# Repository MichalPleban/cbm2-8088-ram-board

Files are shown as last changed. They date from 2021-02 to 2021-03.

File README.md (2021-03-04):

# CBM-II 8088 CPU + RAM expansion board

## About the project

This repository is the hardware part of the project to create a PC compatibility system for Commodore CBM-II computers. The software counterpart is located at:

https://github.com/MichalPleban/cbm2-pc-emulator

More information about the project can be found at:

http://www.cbm-ii.com/

## About the board

The board is a replica of the original 8088 processor board for Commodore CBM-II computers. The replica is 100% compatible with the original card, so you can still run original MS-DOS 1.25 or CP/M-86 1.1 on it.

Several additional features were added to the card which allow for building a system that has enough power to run modern versions of DOS and DOS software:

### Fixed stability problems

The original card has serious stability problems in many machines, and it simply refuses to run on most low-profile CBM-II computers. These problems are caused by noise on /ERAS and /ECAS signals which cause memory corruption. Depending on the computer motherboard and/or PLA, the card may either work without any problems, hang once every few minutes or simply not work at all.

These problems are removed in the replica, and it works in all CBM-II computers.

### 1 MB memory expansion

The expanded memory is visible to both CPUs and allows DOS to access full 640 kB of memory – running DOS in only 256 kB leaves too little room for almost any application. The 64 kB segments above the 640 kB barrier can be individually turned off to allow other hardware (such as ISA graphics cards) to map into the address space.

The card has also the cartridge ROM with “fast boot” KERNAL modifications, thanks to which the memory test during powerup is greatly shortened (the test of 1 MB memory with the original would take around 2 minutes – this is shortened to mere 4 seconds).

### 12 MHz system clock

The card is equipped with a clock generator that produces either 12 MHz system clock with 50% duty cycle (for the NEC V20 processor) or 8 MHz clock with 33% duty cycle (for the 8088 processor). Compared with the 5 MHz on the original card, it gives a much faster system.
The system speed is further increased by using SRAM chips, which do not require refresh. Therefore the memory refresh system does not steal cycles from the CPU like on the original card.

### Hardware SPI interface

The SPI system is used to create a fast interface to a SD card, which serves as a 8 GB hard disk. Because the interface is implemented in hardware using shift registers, in combination with the INS/OUTS instructions of the NEC V20 CPU, it allows for theoretical read and write speed exceeding 1 MB / s.

### Battery backed RTC clock

The clock keeps the date and time for DOS and has also a few bytes of battery backed NVRAM to hold persistent configuration data.

### Reprogrammable EEPROM

The PC compatibility software is stored in an EEPROM chip, which can be reprogrammed from the 8088 side. Thanks to this, The library can be upgraded just by putting a newer version on the SD card and running the upgrade program from within DOS.

Having the whole software in the EEPROM allows also for diskless boot – the whole software is loaded from ROM, not from the disk like with the original card.

### Expansion port

The expansion port contains all the CPU bus signals, which should make it possible to add an ISA interface in the future. A smaller port with just the SPI and I2C signals is also available for additional hardware expansions in the future.

### Support for hardware virtualization

The card can generate NMI signal whenever an I/O port is accessed by the 8088 CPU. The I/O port access and the value being written to it are stored in hardware latches, so that the NMI routine can determine which I/O port was accessed and perform appropriate actions to simulate the hardware.

A video memory access latch was also added, which holds information about which parts of the video buffer at segment 0B000h was modified. This information speeds up screen refresh, because only the modified parts are being refreshed.

### 8087 coprocessor compatibility
The original card had a bug, due to which using the 8087 FPU was not possible – the card would lock up when the FPU was inserted into its socket. This bug has been fixed in the replica.

### Unobtainable chips replaced

The original card uses the 6525 Tri-Port Interface chip which is impossible to obtain. It has been replaced by an 8255 chip.

### Cartridge ROM sockets
The card has sockets for cartridge ROM or RAM at $4000, $6000 and $C000 which allow using  existing cartridge images. If a cartridge ROM is present, the card boot menu allows selecting whether to boot into BASIC or start the cartridge.

## Building the card

The PCB of the board has 4 layers to make it smaller and fit into the small space inside the low-profile CBM-II machines. Check with your PCB factory if they can make a 4 layer PCB for you.

The board contains an Atmel ATF1508 CPLD chip. You need a suitable programmer, such as ATF15xx-DK2, to program the chip. The board has a JEDEC connector which can be used to connect to the programmer directly. Use the cobalt.jed file from the repository to program the chip.

There are two ROM images in the archive which are necessary for the card to work:
-	8088.bin – 27C512 chip image to be placed at U7D
-	6509.bin  - 27C64 chip image to be placed at U2C

There are also chargen_lp.bin and chargen_hp.bin images which can be used to replace the character ROM in your machine (correspondently for low-profile and high-profile machines). They contain an alternate character set with some characters that are useful when running DOS (such as the backspace character). The card must be configured to use this character set – press F10 after booting the card.

The freedos.zip archive contains an image of a bootable FreeDOS hard disk. Put this image onto an SD card that is at least 8 GB of size (there are several SD card imaging applications available, I am using Win32 Disk Imager). After writing the images, the SD card will be readable on your PC, so you can easily add other applications. Note that you must use this image to boot the 8088 card, because the SD card must be formatted with special geometry for the INT 13h functions in the 8088 BIOS.

The ROM image from the repository contains the current version of the PC compatibility library. If you want to update the library in the future, grab the upgrade.com file from the repository, put it on the SD card and run it in DOS – it will write the newest version to the EEPROM chip on the board.

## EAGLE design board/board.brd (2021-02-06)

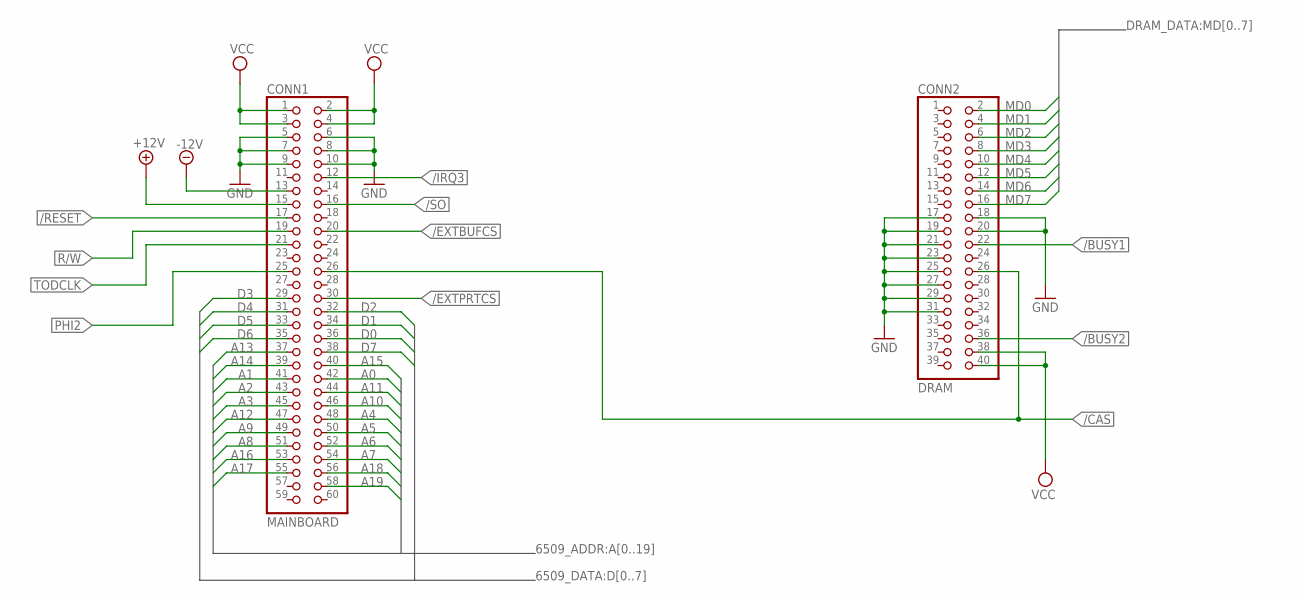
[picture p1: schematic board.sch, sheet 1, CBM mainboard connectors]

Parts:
CONN1: MAINBOARD; 2X30
CONN2: DRAM; 2X20

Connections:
+12V: CONN1.15; also elsewhere on the board
-12V: CONN1.13; also elsewhere on the board
/BUSY1: CONN2.22; also elsewhere on the board
/BUSY2: CONN2.36; also elsewhere on the board
/CAS: CONN1.26, CONN2.26; also elsewhere on the board
/EXTBUFCS: CONN1.20; also elsewhere on the board
/EXTPRTCS: CONN1.30; also elsewhere on the board
/IRQ3: CONN1.12; also elsewhere on the board
/RESET: CONN1.17; also elsewhere on the board
/SO: CONN1.16; also elsewhere on the board
A0: CONN1.42; also elsewhere on the board
A1: CONN1.41; also elsewhere on the board
A2: CONN1.43; also elsewhere on the board
A3: CONN1.45; also elsewhere on the board
A4: CONN1.48; also elsewhere on the board
A5: CONN1.50; also elsewhere on the board
A6: CONN1.52; also elsewhere on the board
A7: CONN1.54; also elsewhere on the board
A8: CONN1.51; also elsewhere on the board
A9: CONN1.49; also elsewhere on the board
A10: CONN1.46; also elsewhere on the board
A11: CONN1.44; also elsewhere on the board
A12: CONN1.47; also elsewhere on the board
A13: CONN1.37; also elsewhere on the board
A14: CONN1.39; also elsewhere on the board
A15: CONN1.40; also elsewhere on the board
A16: CONN1.53; also elsewhere on the board
A17: CONN1.55; also elsewhere on the board
A18: CONN1.56; also elsewhere on the board
A19: CONN1.58; also elsewhere on the board
D0: CONN1.36; also elsewhere on the board
D1: CONN1.34; also elsewhere on the board
D2: CONN1.32; also elsewhere on the board
D3: CONN1.29; also elsewhere on the board
D4: CONN1.31; also elsewhere on the board
D5: CONN1.33; also elsewhere on the board
D6: CONN1.35; also elsewhere on the board
D7: CONN1.38; also elsewhere on the board
GND: CONN1.5, CONN1.6, CONN1.7, CONN1.8, CONN1.9, CONN1.10, CONN2.17, CONN2.18, CONN2.19, CONN2.20, CONN2.21, CONN2.23, CONN2.25, CONN2.27, CONN2.29, CONN2.31; also elsewhere on the board
MD0: CONN2.2; also elsewhere on the board
MD1: CONN2.4; also elsewhere on the board
MD2: CONN2.6; also elsewhere on the board
MD3: CONN2.8; also elsewhere on the board
MD4: CONN2.10; also elsewhere on the board
MD5: CONN2.12; also elsewhere on the board
MD6: CONN2.14; also elsewhere on the board
MD7: CONN2.16; also elsewhere on the board
PHI2: CONN1.25; also elsewhere on the board
R/W: CONN1.19; also elsewhere on the board
TODCLK: CONN1.21; also elsewhere on the board
VCC: CONN1.1, CONN1.2, CONN1.3, CONN1.4, CONN2.38, CONN2.40; also elsewhere on the board

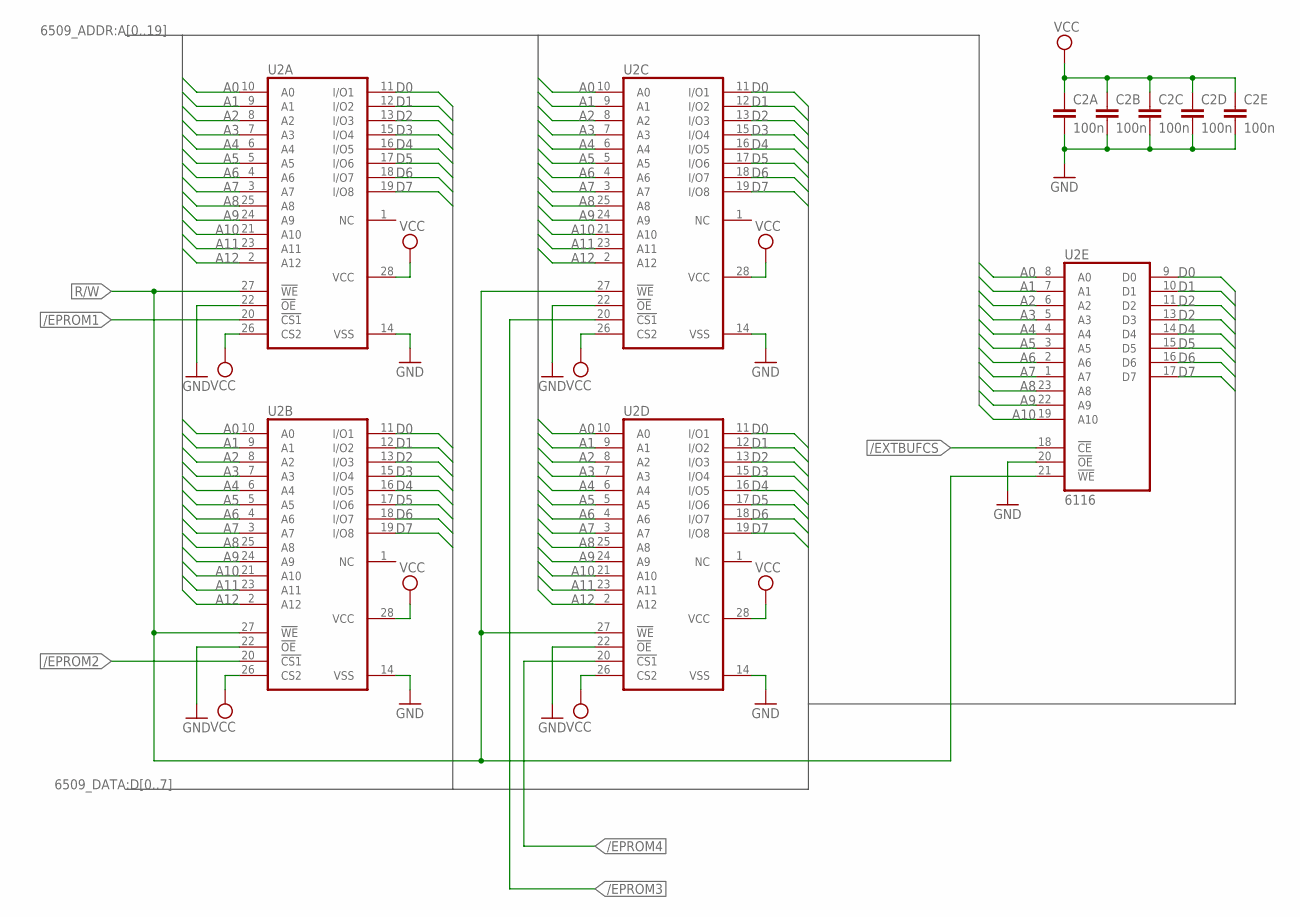
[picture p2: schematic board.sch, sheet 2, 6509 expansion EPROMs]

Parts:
C2A, C2B, C2C, C2D, C2E: 100n; C050-025X075
U2A, U2B, U2C, U2D: 6264A; DIL28-6
U2E: 6116; DIL24

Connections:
/EPROM1: U2A.20 (!CS1); also elsewhere on the board
/EPROM2: U2B.20 (!CS1); also elsewhere on the board
/EPROM3: U2C.20 (!CS1); also elsewhere on the board
/EPROM4: U2D.20 (!CS1); also elsewhere on the board
/EXTBUFCS: U2E.18 (!CE); also elsewhere on the board
A0: U2A.10 (A0), U2B.10 (A0), U2C.10 (A0), U2D.10 (A0), U2E.8 (A0); also elsewhere on the board
A1: U2A.9 (A1), U2B.9 (A1), U2C.9 (A1), U2D.9 (A1), U2E.7 (A1); also elsewhere on the board
A2: U2A.8 (A2), U2B.8 (A2), U2C.8 (A2), U2D.8 (A2), U2E.6 (A2); also elsewhere on the board
A3: U2A.7 (A3), U2B.7 (A3), U2C.7 (A3), U2D.7 (A3), U2E.5 (A3); also elsewhere on the board
A4: U2A.6 (A4), U2B.6 (A4), U2C.6 (A4), U2D.6 (A4), U2E.4 (A4); also elsewhere on the board
A5: U2A.5 (A5), U2B.5 (A5), U2C.5 (A5), U2D.5 (A5), U2E.3 (A5); also elsewhere on the board
A6: U2A.4 (A6), U2B.4 (A6), U2C.4 (A6), U2D.4 (A6), U2E.2 (A6); also elsewhere on the board
A7: U2A.3 (A7), U2B.3 (A7), U2C.3 (A7), U2D.3 (A7), U2E.1 (A7); also elsewhere on the board
A8: U2A.25 (A8), U2B.25 (A8), U2C.25 (A8), U2D.25 (A8), U2E.23 (A8); also elsewhere on the board
A9: U2A.24 (A9), U2B.24 (A9), U2C.24 (A9), U2D.24 (A9), U2E.22 (A9); also elsewhere on the board
A10: U2A.21 (A10), U2B.21 (A10), U2C.21 (A10), U2D.21 (A10), U2E.19 (A10); also elsewhere on the board
A11: U2A.23 (A11), U2B.23 (A11), U2C.23 (A11), U2D.23 (A11); also elsewhere on the board
A12: U2A.2 (A12), U2B.2 (A12), U2C.2 (A12), U2D.2 (A12); also elsewhere on the board
D0: U2A.11 (I/O1), U2B.11 (I/O1), U2C.11 (I/O1), U2D.11 (I/O1), U2E.9 (D0); also elsewhere on the board
D1: U2A.12 (I/O2), U2B.12 (I/O2), U2C.12 (I/O2), U2D.12 (I/O2), U2E.10 (D1); also elsewhere on the board
D2: U2A.13 (I/O3), U2B.13 (I/O3), U2C.13 (I/O3), U2D.13 (I/O3), U2E.11 (D2); also elsewhere on the board
D3: U2A.15 (I/O4), U2B.15 (I/O4), U2C.15 (I/O4), U2D.15 (I/O4), U2E.13 (D3); also elsewhere on the board
D4: U2A.16 (I/O5), U2B.16 (I/O5), U2C.16 (I/O5), U2D.16 (I/O5), U2E.14 (D4); also elsewhere on the board
D5: U2A.17 (I/O6), U2B.17 (I/O6), U2C.17 (I/O6), U2D.17 (I/O6), U2E.15 (D5); also elsewhere on the board
D6: U2A.18 (I/O7), U2B.18 (I/O7), U2C.18 (I/O7), U2D.18 (I/O7), U2E.16 (D6); also elsewhere on the board
D7: U2A.19 (I/O8), U2B.19 (I/O8), U2C.19 (I/O8), U2D.19 (I/O8), U2E.17 (D7); also elsewhere on the board
GND: C2A.2, C2B.2, C2C.2, C2D.2, C2E.2, U2A.14 (VSS), U2A.22 (!OE), U2B.14 (VSS), U2B.22 (!OE), U2C.14 (VSS), U2C.22 (!OE), U2D.14 (VSS), U2D.22 (!OE), U2E.12 (GND), U2E.20 (!OE); also elsewhere on the board
R/W: U2A.27 (!WE), U2B.27 (!WE), U2C.27 (!WE), U2D.27 (!WE), U2E.21 (!WE); also elsewhere on the board
VCC: C2A.1, C2B.1, C2C.1, C2D.1, C2E.1, U2A.26 (CS2), U2A.28 (VCC), U2B.26 (CS2), U2B.28 (VCC), U2C.26 (CS2), U2C.28 (VCC), U2D.26 (CS2), U2D.28 (VCC), U2E.24 (VCC); also elsewhere on the board

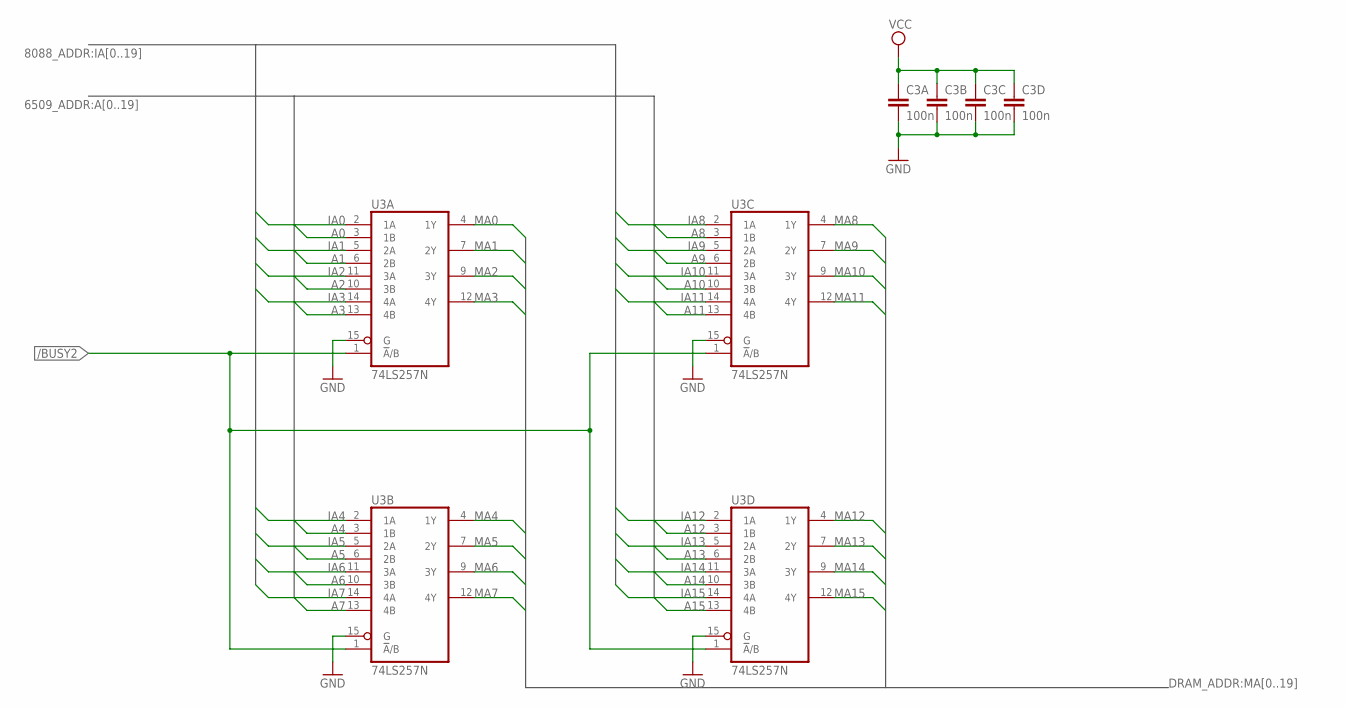
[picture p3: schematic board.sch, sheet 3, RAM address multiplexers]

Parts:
C3A, C3B, C3C, C3D: 100n; C050-025X075
U3A, U3B, U3C, U3D: 74LS257N; DIL16

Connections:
/BUSY2: U3A.1 (!A!/B), U3B.1 (!A!/B), U3C.1 (!A!/B), U3D.1 (!A!/B); also elsewhere on the board
A0: U3A.3 (1B); also elsewhere on the board
A1: U3A.6 (2B); also elsewhere on the board
A2: U3A.10 (3B); also elsewhere on the board
A3: U3A.13 (4B); also elsewhere on the board
A4: U3B.3 (1B); also elsewhere on the board
A5: U3B.6 (2B); also elsewhere on the board
A6: U3B.10 (3B); also elsewhere on the board
A7: U3B.13 (4B); also elsewhere on the board
A8: U3C.3 (1B); also elsewhere on the board
A9: U3C.6 (2B); also elsewhere on the board
A10: U3C.10 (3B); also elsewhere on the board
A11: U3C.13 (4B); also elsewhere on the board
A12: U3D.3 (1B); also elsewhere on the board
A13: U3D.6 (2B); also elsewhere on the board
A14: U3D.10 (3B); also elsewhere on the board
A15: U3D.13 (4B); also elsewhere on the board
GND: C3A.2, C3B.2, C3C.2, C3D.2, U3A.8 (GND), U3A.15 (G), U3B.8 (GND), U3B.15 (G), U3C.8 (GND), U3C.15 (G), U3D.8 (GND), U3D.15 (G); also elsewhere on the board
IA0: U3A.2 (1A); also elsewhere on the board
IA1: U3A.5 (2A); also elsewhere on the board
IA2: U3A.11 (3A); also elsewhere on the board
IA3: U3A.14 (4A); also elsewhere on the board
IA4: U3B.2 (1A); also elsewhere on the board
IA5: U3B.5 (2A); also elsewhere on the board
IA6: U3B.11 (3A); also elsewhere on the board
IA7: U3B.14 (4A); also elsewhere on the board
IA8: U3C.2 (1A); also elsewhere on the board
IA9: U3C.5 (2A); also elsewhere on the board
IA10: U3C.11 (3A); also elsewhere on the board
IA11: U3C.14 (4A); also elsewhere on the board
IA12: U3D.2 (1A); also elsewhere on the board
IA13: U3D.5 (2A); also elsewhere on the board
IA14: U3D.11 (3A); also elsewhere on the board
IA15: U3D.14 (4A); also elsewhere on the board
MA0: U3A.4 (1Y); also elsewhere on the board
MA1: U3A.7 (2Y); also elsewhere on the board
MA2: U3A.9 (3Y); also elsewhere on the board
MA3: U3A.12 (4Y); also elsewhere on the board
MA4: U3B.4 (1Y); also elsewhere on the board
MA5: U3B.7 (2Y); also elsewhere on the board
MA6: U3B.9 (3Y); also elsewhere on the board
MA7: U3B.12 (4Y); also elsewhere on the board
MA8: U3C.4 (1Y); also elsewhere on the board
MA9: U3C.7 (2Y); also elsewhere on the board
MA10: U3C.9 (3Y); also elsewhere on the board
MA11: U3C.12 (4Y); also elsewhere on the board
MA12: U3D.4 (1Y); also elsewhere on the board
MA13: U3D.7 (2Y); also elsewhere on the board
MA14: U3D.9 (3Y); also elsewhere on the board
MA15: U3D.12 (4Y); also elsewhere on the board
VCC: C3A.1, C3B.1, C3C.1, C3D.1, U3A.16 (VCC), U3B.16 (VCC), U3C.16 (VCC), U3D.16 (VCC); also elsewhere on the board

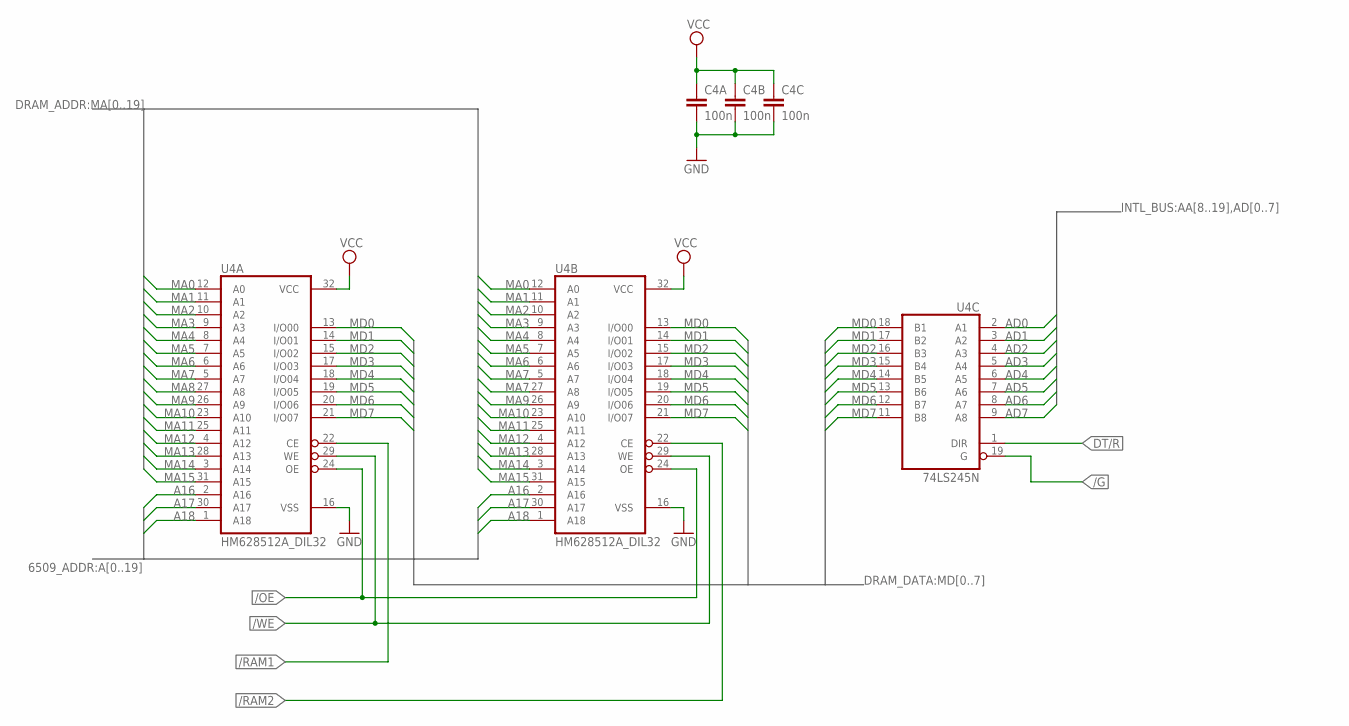
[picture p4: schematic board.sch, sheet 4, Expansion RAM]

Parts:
C4A, C4B, C4C: 100n; C050-025X075
U4A, U4B: HM628512A_DIL32; DIL32
U4C: 74LS245N; DIL20

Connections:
/G: U4C.19 (G); also elsewhere on the board
/OE: U4A.24 (OE), U4B.24 (OE); also elsewhere on the board
/RAM1: U4A.22 (CE); also elsewhere on the board
/RAM2: U4B.22 (CE); also elsewhere on the board
/WE: U4A.29 (WE), U4B.29 (WE); also elsewhere on the board
A16: U4A.2 (A16), U4B.2 (A16); also elsewhere on the board
A17: U4A.30 (A17), U4B.30 (A17); also elsewhere on the board
A18: U4A.1 (A18), U4B.1 (A18); also elsewhere on the board
AD0: U4C.2 (A1); also elsewhere on the board
AD1: U4C.3 (A2); also elsewhere on the board
AD2: U4C.4 (A3); also elsewhere on the board
AD3: U4C.5 (A4); also elsewhere on the board
AD4: U4C.6 (A5); also elsewhere on the board
AD5: U4C.7 (A6); also elsewhere on the board
AD6: U4C.8 (A7); also elsewhere on the board
AD7: U4C.9 (A8); also elsewhere on the board
DT/R: U4C.1 (DIR); also elsewhere on the board
GND: C4A.2, C4B.2, C4C.2, U4A.16 (VSS), U4B.16 (VSS), U4C.10 (GND); also elsewhere on the board
MA0: U4A.12 (A0), U4B.12 (A0); also elsewhere on the board
MA1: U4A.11 (A1), U4B.11 (A1); also elsewhere on the board
MA2: U4A.10 (A2), U4B.10 (A2); also elsewhere on the board
MA3: U4A.9 (A3), U4B.9 (A3); also elsewhere on the board
MA4: U4A.8 (A4), U4B.8 (A4); also elsewhere on the board
MA5: U4A.7 (A5), U4B.7 (A5); also elsewhere on the board
MA6: U4A.6 (A6), U4B.6 (A6); also elsewhere on the board
MA7: U4A.5 (A7), U4B.5 (A7); also elsewhere on the board
MA8: U4A.27 (A8), U4B.27 (A8); also elsewhere on the board
MA9: U4A.26 (A9), U4B.26 (A9); also elsewhere on the board
MA10: U4A.23 (A10), U4B.23 (A10); also elsewhere on the board
MA11: U4A.25 (A11), U4B.25 (A11); also elsewhere on the board
MA12: U4A.4 (A12), U4B.4 (A12); also elsewhere on the board
MA13: U4A.28 (A13), U4B.28 (A13); also elsewhere on the board
MA14: U4A.3 (A14), U4B.3 (A14); also elsewhere on the board
MA15: U4A.31 (A15), U4B.31 (A15); also elsewhere on the board
MD0: U4A.13 (I/O00), U4B.13 (I/O00), U4C.18 (B1); also elsewhere on the board
MD1: U4A.14 (I/O01), U4B.14 (I/O01), U4C.17 (B2); also elsewhere on the board
MD2: U4A.15 (I/O02), U4B.15 (I/O02), U4C.16 (B3); also elsewhere on the board
MD3: U4A.17 (I/O03), U4B.17 (I/O03), U4C.15 (B4); also elsewhere on the board
MD4: U4A.18 (I/O04), U4B.18 (I/O04), U4C.14 (B5); also elsewhere on the board
MD5: U4A.19 (I/O05), U4B.19 (I/O05), U4C.13 (B6); also elsewhere on the board
MD6: U4A.20 (I/O06), U4B.20 (I/O06), U4C.12 (B7); also elsewhere on the board
MD7: U4A.21 (I/O07), U4B.21 (I/O07), U4C.11 (B8); also elsewhere on the board
VCC: C4A.1, C4B.1, C4C.1, U4A.32 (VCC), U4B.32 (VCC), U4C.20 (VCC); also elsewhere on the board

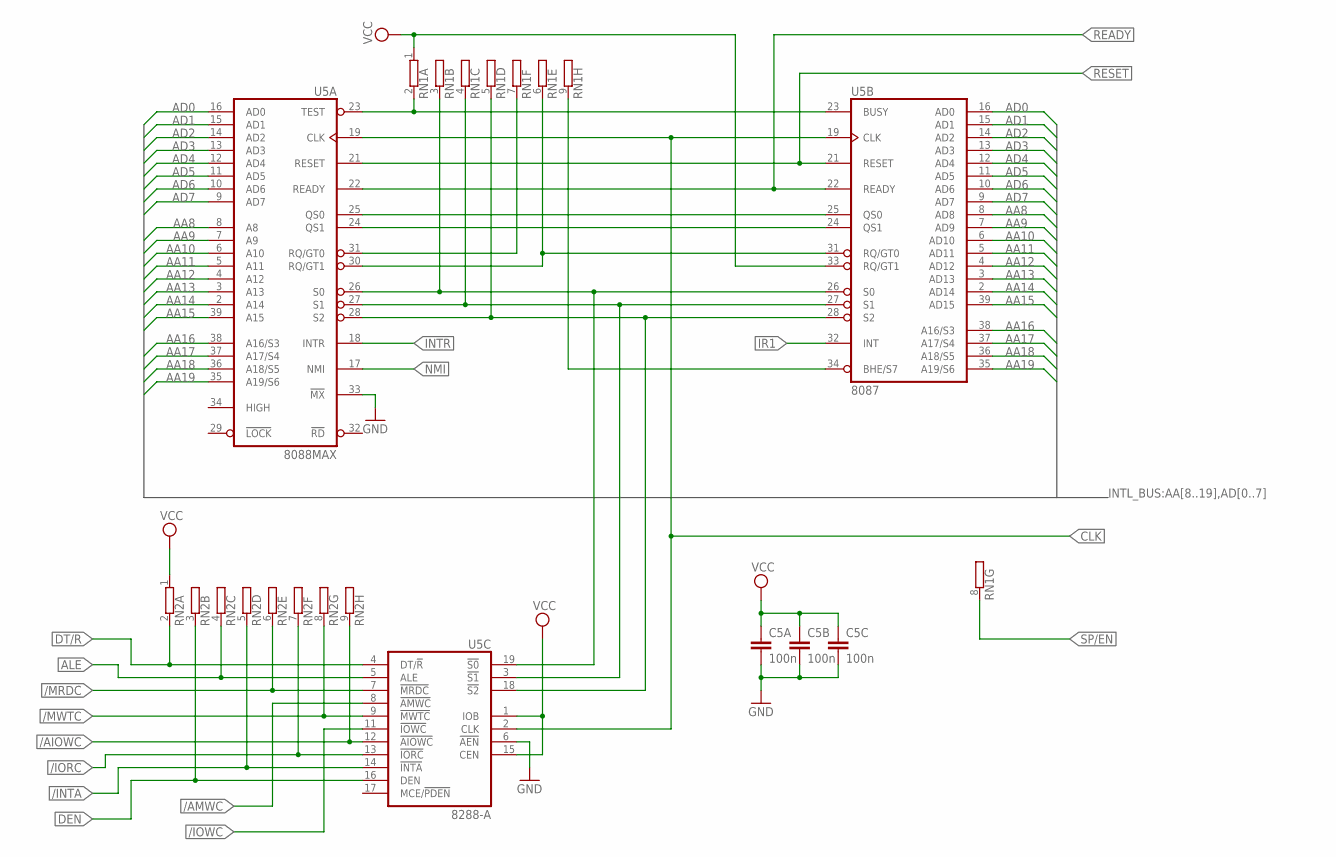
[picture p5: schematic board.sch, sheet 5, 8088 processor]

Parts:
C5A, C5B, C5C: 100n; C050-025X075
RN1, RN2: GE08R; SIL9
U5A: 8088MAX; DIL40
U5B: 8087; DIL40
U5C: 8288-A; DIL20

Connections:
/AIOWC: RN2.9 (2), U5C.12 (!AIOWC); also elsewhere on the board
/AMWC: U5C.8 (!AMWC); also elsewhere on the board
/INTA: RN2.5 (2), U5C.14 (!INTA); also elsewhere on the board
/IORC: RN2.7 (2), U5C.13 (!IORC); also elsewhere on the board
/IOWC: U5C.11 (!IOWC); also elsewhere on the board
/MRDC: RN2.6 (2), U5C.7 (!MRDC); also elsewhere on the board
/MWTC: RN2.8 (2), U5C.9 (!MWTC); also elsewhere on the board
/TEST: RN1.2, U5A.23 (TEST), U5B.23 (BUSY)
AA8: U5A.8 (A8), U5B.8 (AD8); also elsewhere on the board
AA9: U5A.7 (A9), U5B.7 (AD9); also elsewhere on the board
AA10: U5A.6 (A10), U5B.6 (AD10); also elsewhere on the board
AA11: U5A.5 (A11), U5B.5 (AD11); also elsewhere on the board
AA12: U5A.4 (A12), U5B.4 (AD12); also elsewhere on the board
AA13: U5A.3 (A13), U5B.3 (AD13); also elsewhere on the board
AA14: U5A.2 (A14), U5B.2 (AD14); also elsewhere on the board
AA15: U5A.39 (A15), U5B.39 (AD15); also elsewhere on the board
AA16: U5A.38 (A16/S3), U5B.38 (A16/S3); also elsewhere on the board
AA17: U5A.37 (A17/S4), U5B.37 (A17/S4); also elsewhere on the board
AA18: U5A.36 (A18/S5), U5B.36 (A18/S5); also elsewhere on the board
AA19: U5A.35 (A19/S6), U5B.35 (A19/S6); also elsewhere on the board
AD0: U5A.16 (AD0), U5B.16 (AD0); also elsewhere on the board
AD1: U5A.15 (AD1), U5B.15 (AD1); also elsewhere on the board
AD2: U5A.14 (AD2), U5B.14 (AD2); also elsewhere on the board
AD3: U5A.13 (AD3), U5B.13 (AD3); also elsewhere on the board
AD4: U5A.12 (AD4), U5B.12 (AD4); also elsewhere on the board
AD5: U5A.11 (AD5), U5B.11 (AD5); also elsewhere on the board
AD6: U5A.10 (AD6), U5B.10 (AD6); also elsewhere on the board
AD7: U5A.9 (AD7), U5B.9 (AD7); also elsewhere on the board
ALE: RN2.4 (2), U5C.5 (ALE); also elsewhere on the board
BHE/S7: RN1.9 (2), U5B.34 (BHE/S7)
CLK: U5A.19 (CLK), U5B.19 (CLK), U5C.2 (CLK); also elsewhere on the board
DEN: RN2.3 (2), U5C.16 (DEN); also elsewhere on the board
DT/R: RN2.2, U5C.4 (DT/!R); also elsewhere on the board
GND: C5A.2, C5B.2, C5C.2, U5A.1 (GND), U5A.20 (GND), U5A.33 (!MX), U5B.1 (GND), U5B.20 (GND), U5C.6 (!AEN), U5C.10 (GND); also elsewhere on the board
INTR: U5A.18 (INTR); also elsewhere on the board
IR1: U5B.32 (INT); also elsewhere on the board
NMI: U5A.17 (NMI); also elsewhere on the board
QS0: U5A.25 (QS0), U5B.25 (QS0)
QS1: U5A.24 (QS1), U5B.24 (QS1)
READY: U5A.22 (READY), U5B.22 (READY); also elsewhere on the board
RESET: U5A.21 (RESET), U5B.21 (RESET); also elsewhere on the board
RQ: RN1.7 (2), U5A.31 (RQ/GT0)
RQ/GT0: RN1.6 (2), U5A.30 (RQ/GT1), U5B.31 (RQ/GT0)
S0: RN1.3 (2), U5A.26 (S0), U5B.26 (S0), U5C.19 (!S0)
S1: RN1.4 (2), U5A.27 (S1), U5B.27 (S1), U5C.3 (!S1)
S2: RN1.5 (2), U5A.28 (S2), U5B.28 (S2), U5C.18 (!S2)
SP/EN: RN1.8 (2); also elsewhere on the board
VCC: C5A.1, C5B.1, C5C.1, RN1.1, RN2.1, U5A.40 (VCC), U5B.33 (RQ/GT1), U5B.40 (VCC), U5C.1 (IOB), U5C.15 (CEN), U5C.20 (VCC); also elsewhere on the board

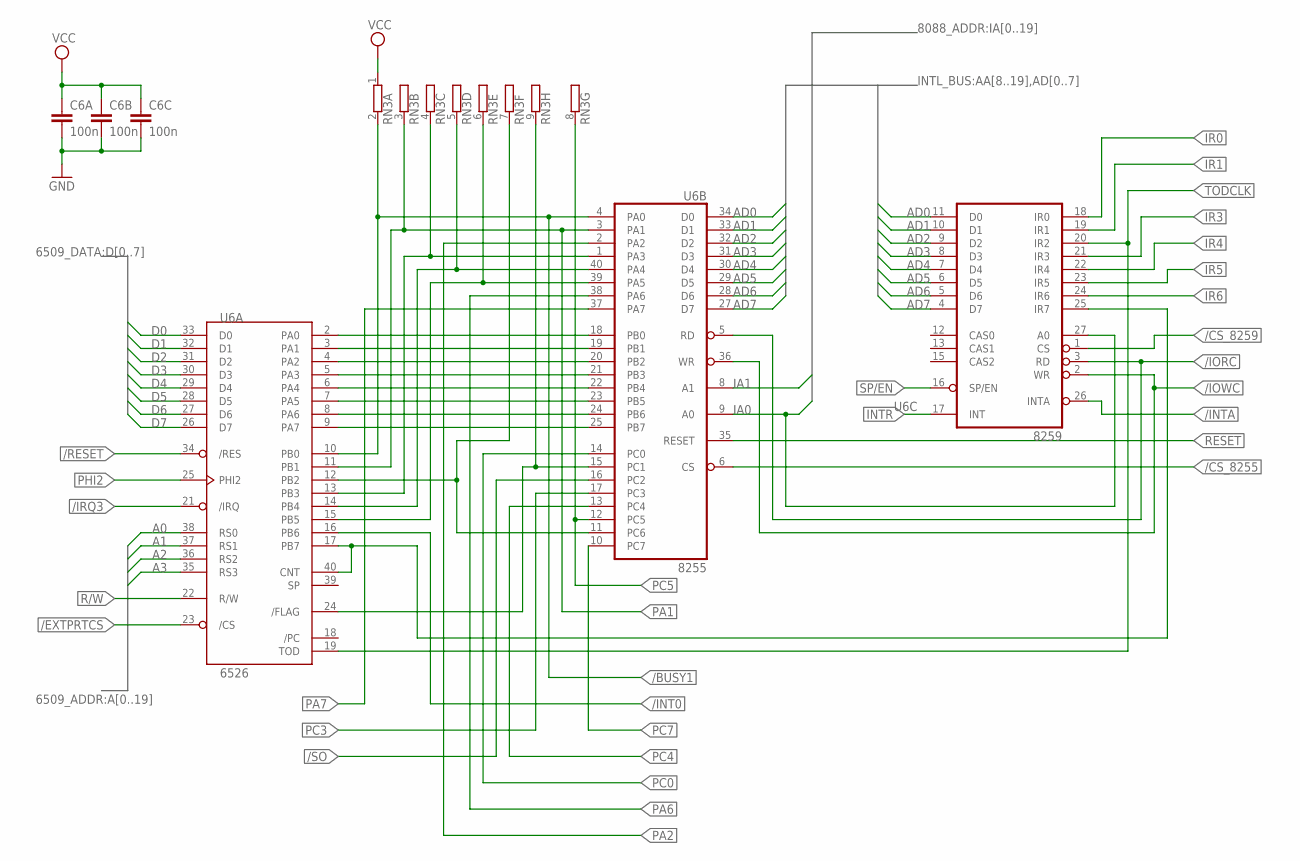
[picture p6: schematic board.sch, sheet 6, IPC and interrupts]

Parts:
C6A, C6B, C6C: 100n; C050-025X075
RN3: GE08R; SIL9
U6A: 6526; DIP40
U6B: 8255; DIL40
U6C: 8259; DIL28-6

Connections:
/BUSY1: RN3.2, U6A.10 (PB0), U6B.4 (PA0); also elsewhere on the board
/CS_8255: U6B.6 (CS); also elsewhere on the board
/CS_8259: U6C.1 (CS); also elsewhere on the board
/EXTPRTCS: U6A.23 (/CS); also elsewhere on the board
/INT0: U6A.16 (PB6); also elsewhere on the board
/INTA: U6C.26 (INTA); also elsewhere on the board
/IORC: U6B.5 (RD), U6C.3 (RD); also elsewhere on the board
/IOWC: U6B.36 (WR), U6C.2 (WR); also elsewhere on the board
/IRQ3: U6A.21 (/IRQ); also elsewhere on the board
/RESET: U6A.34 (/RES); also elsewhere on the board
/SO: U6B.16 (PC2); also elsewhere on the board
A0: U6A.38 (RS0); also elsewhere on the board
A1: U6A.37 (RS1); also elsewhere on the board
A2: U6A.36 (RS2); also elsewhere on the board
A3: U6A.35 (RS3); also elsewhere on the board
AD0: U6B.34 (D0), U6C.11 (D0); also elsewhere on the board
AD1: U6B.33 (D1), U6C.10 (D1); also elsewhere on the board
AD2: U6B.32 (D2), U6C.9 (D2); also elsewhere on the board
AD3: U6B.31 (D3), U6C.8 (D3); also elsewhere on the board
AD4: U6B.30 (D4), U6C.7 (D4); also elsewhere on the board
AD5: U6B.29 (D5), U6C.6 (D5); also elsewhere on the board
AD6: U6B.28 (D6), U6C.5 (D6); also elsewhere on the board
AD7: U6B.27 (D7), U6C.4 (D7); also elsewhere on the board
D0: U6A.33 (D0); also elsewhere on the board
D1: U6A.32 (D1); also elsewhere on the board
D2: U6A.31 (D2); also elsewhere on the board
D3: U6A.30 (D3); also elsewhere on the board
D4: U6A.29 (D4); also elsewhere on the board
D5: U6A.28 (D5); also elsewhere on the board
D6: U6A.27 (D6); also elsewhere on the board
D7: U6A.26 (D7); also elsewhere on the board
GND: C6A.2, C6B.2, C6C.2, U6A.1 (GND), U6B.7 (GND), U6C.14 (GND); also elsewhere on the board
IA0: U6B.9 (A0), U6C.27 (A0); also elsewhere on the board
IA1: U6B.8 (A1); also elsewhere on the board
INTR: U6C.17 (INT); also elsewhere on the board
IR0: U6C.18 (IR0); also elsewhere on the board
IR1: U6C.19 (IR1); also elsewhere on the board
IR3: U6C.21 (IR3); also elsewhere on the board
IR4: U6C.22 (IR4); also elsewhere on the board
IR5: U6C.23 (IR5); also elsewhere on the board
IR6: U6C.24 (IR6); also elsewhere on the board
IR7: U6A.17 (PB7), U6A.40 (CNT), U6C.25 (IR7)
PA1: RN3.3 (2), U6A.11 (PB1), U6B.3 (PA1); also elsewhere on the board
PA2: U6B.2 (PA2); also elsewhere on the board
PA3: RN3.4 (2), U6A.13 (PB3), U6B.1 (PA3)
PA4: RN3.5 (2), U6A.14 (PB4), U6B.40 (PA4)
PA5: RN3.6 (2), U6A.15 (PB5), U6B.39 (PA5)
PA6: U6B.38 (PA6); also elsewhere on the board
PA7: U6B.37 (PA7); also elsewhere on the board
PB0: U6A.2 (PA0), U6B.18 (PB0)
PB1: U6A.3 (PA1), U6B.19 (PB1)
PB2: U6A.4 (PA2), U6B.20 (PB2)
PB3: U6A.5 (PA3), U6B.21 (PB3)
PB4: U6A.6 (PA4), U6B.22 (PB4)
PB5: U6A.7 (PA5), U6B.23 (PB5)
PB6: U6A.8 (PA6), U6B.24 (PB6)
PB7: U6A.9 (PA7), U6B.25 (PB7)
PC0: U6B.14 (PC0); also elsewhere on the board
PC1: RN3.9 (2), U6A.24 (/FLAG), U6B.15 (PC1)
PC3: U6B.17 (PC3); also elsewhere on the board
PC4: U6B.13 (PC4); also elsewhere on the board
PC5: RN3.8 (2), U6B.12 (PC5); also elsewhere on the board
PC6: RN3.7 (2), U6A.12 (PB2), U6B.11 (PC6)
PC7: U6B.10 (PC7); also elsewhere on the board
PHI2: U6A.25 (PHI2); also elsewhere on the board
R/W: U6A.22 (R/W); also elsewhere on the board
RESET: U6B.35 (RESET); also elsewhere on the board
SP/EN: U6C.16 (SP/EN); also elsewhere on the board
TODCLK: U6A.19 (TOD), U6C.20 (IR2); also elsewhere on the board
VCC: C6A.1, C6B.1, C6C.1, RN3.1, U6A.20 (VCC), U6B.26 (VCC), U6C.28 (VCC); also elsewhere on the board

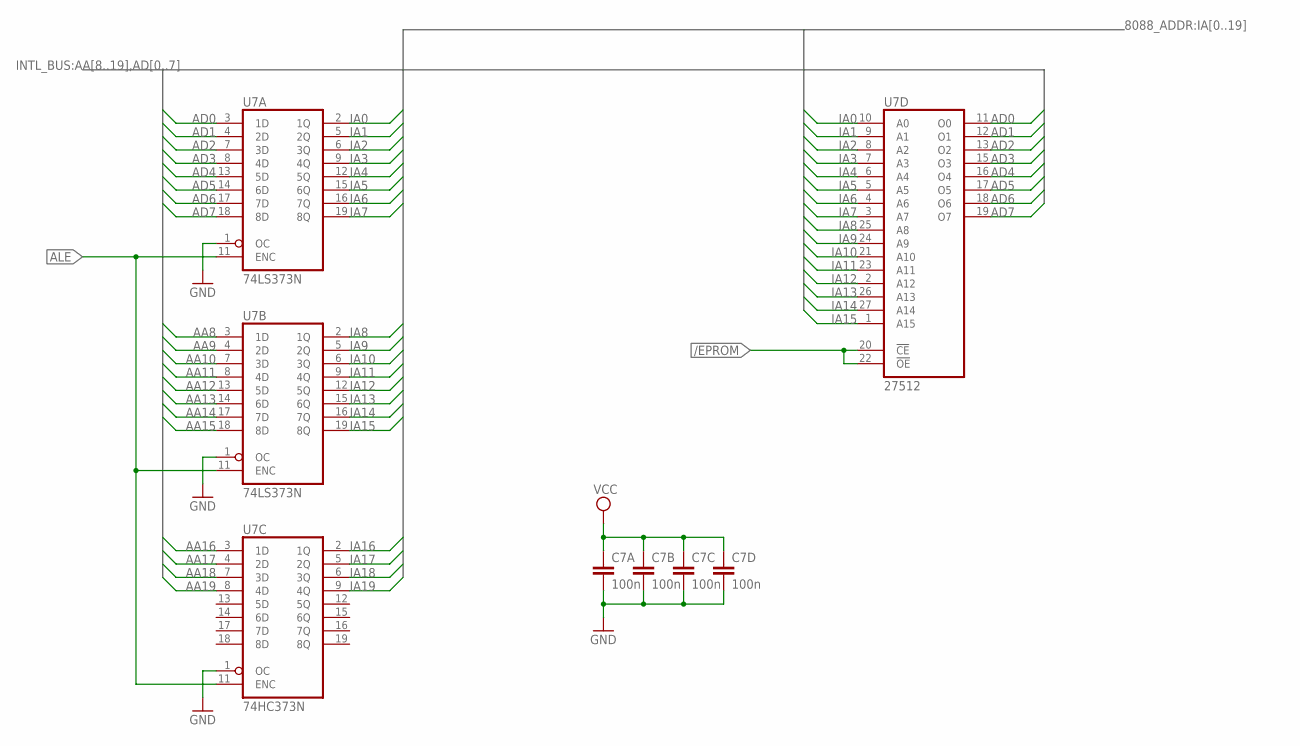
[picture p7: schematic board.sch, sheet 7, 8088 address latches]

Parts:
C7A, C7B, C7C, C7D: 100n; C050-025X075
U7A, U7B: 74LS373N; DIL20
U7C: 74HC373N; DIL20
U7D: 27512; DIL28

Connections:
/EPROM: U7D.20 (!CE), U7D.22 (!OE); also elsewhere on the board
AA8: U7B.3 (1D); also elsewhere on the board
AA9: U7B.4 (2D); also elsewhere on the board
AA10: U7B.7 (3D); also elsewhere on the board
AA11: U7B.8 (4D); also elsewhere on the board
AA12: U7B.13 (5D); also elsewhere on the board
AA13: U7B.14 (6D); also elsewhere on the board
AA14: U7B.17 (7D); also elsewhere on the board
AA15: U7B.18 (8D); also elsewhere on the board
AA16: U7C.3 (1D); also elsewhere on the board
AA17: U7C.4 (2D); also elsewhere on the board
AA18: U7C.7 (3D); also elsewhere on the board
AA19: U7C.8 (4D); also elsewhere on the board
AD0: U7A.3 (1D), U7D.11 (O0); also elsewhere on the board
AD1: U7A.4 (2D), U7D.12 (O1); also elsewhere on the board
AD2: U7A.7 (3D), U7D.13 (O2); also elsewhere on the board
AD3: U7A.8 (4D), U7D.15 (O3); also elsewhere on the board
AD4: U7A.13 (5D), U7D.16 (O4); also elsewhere on the board
AD5: U7A.14 (6D), U7D.17 (O5); also elsewhere on the board
AD6: U7A.17 (7D), U7D.18 (O6); also elsewhere on the board
AD7: U7A.18 (8D), U7D.19 (O7); also elsewhere on the board
ALE: U7A.11 (ENC), U7B.11 (ENC), U7C.11 (ENC); also elsewhere on the board
GND: C7A.2, C7B.2, C7C.2, C7D.2, U7A.1 (OC), U7A.10 (GND), U7B.1 (OC), U7B.10 (GND), U7C.1 (OC), U7C.10 (GND), U7D.14 (GND); also elsewhere on the board
IA0: U7A.2 (1Q), U7D.10 (A0); also elsewhere on the board
IA1: U7A.5 (2Q), U7D.9 (A1); also elsewhere on the board
IA2: U7A.6 (3Q), U7D.8 (A2); also elsewhere on the board
IA3: U7A.9 (4Q), U7D.7 (A3); also elsewhere on the board
IA4: U7A.12 (5Q), U7D.6 (A4); also elsewhere on the board
IA5: U7A.15 (6Q), U7D.5 (A5); also elsewhere on the board
IA6: U7A.16 (7Q), U7D.4 (A6); also elsewhere on the board
IA7: U7A.19 (8Q), U7D.3 (A7); also elsewhere on the board
IA8: U7B.2 (1Q), U7D.25 (A8); also elsewhere on the board
IA9: U7B.5 (2Q), U7D.24 (A9); also elsewhere on the board
IA10: U7B.6 (3Q), U7D.21 (A10); also elsewhere on the board
IA11: U7B.9 (4Q), U7D.23 (A11); also elsewhere on the board
IA12: U7B.12 (5Q), U7D.2 (A12); also elsewhere on the board
IA13: U7B.15 (6Q), U7D.26 (A13); also elsewhere on the board
IA14: U7B.16 (7Q), U7D.27 (A14); also elsewhere on the board
IA15: U7B.19 (8Q), U7D.1 (A15); also elsewhere on the board
IA16: U7C.2 (1Q); also elsewhere on the board
IA17: U7C.5 (2Q); also elsewhere on the board
IA18: U7C.6 (3Q); also elsewhere on the board
IA19: U7C.9 (4Q); also elsewhere on the board
VCC: C7A.1, C7B.1, C7C.1, C7D.1, U7A.20 (VCC), U7B.20 (VCC), U7C.20 (VCC), U7D.28 (VCC); also elsewhere on the board

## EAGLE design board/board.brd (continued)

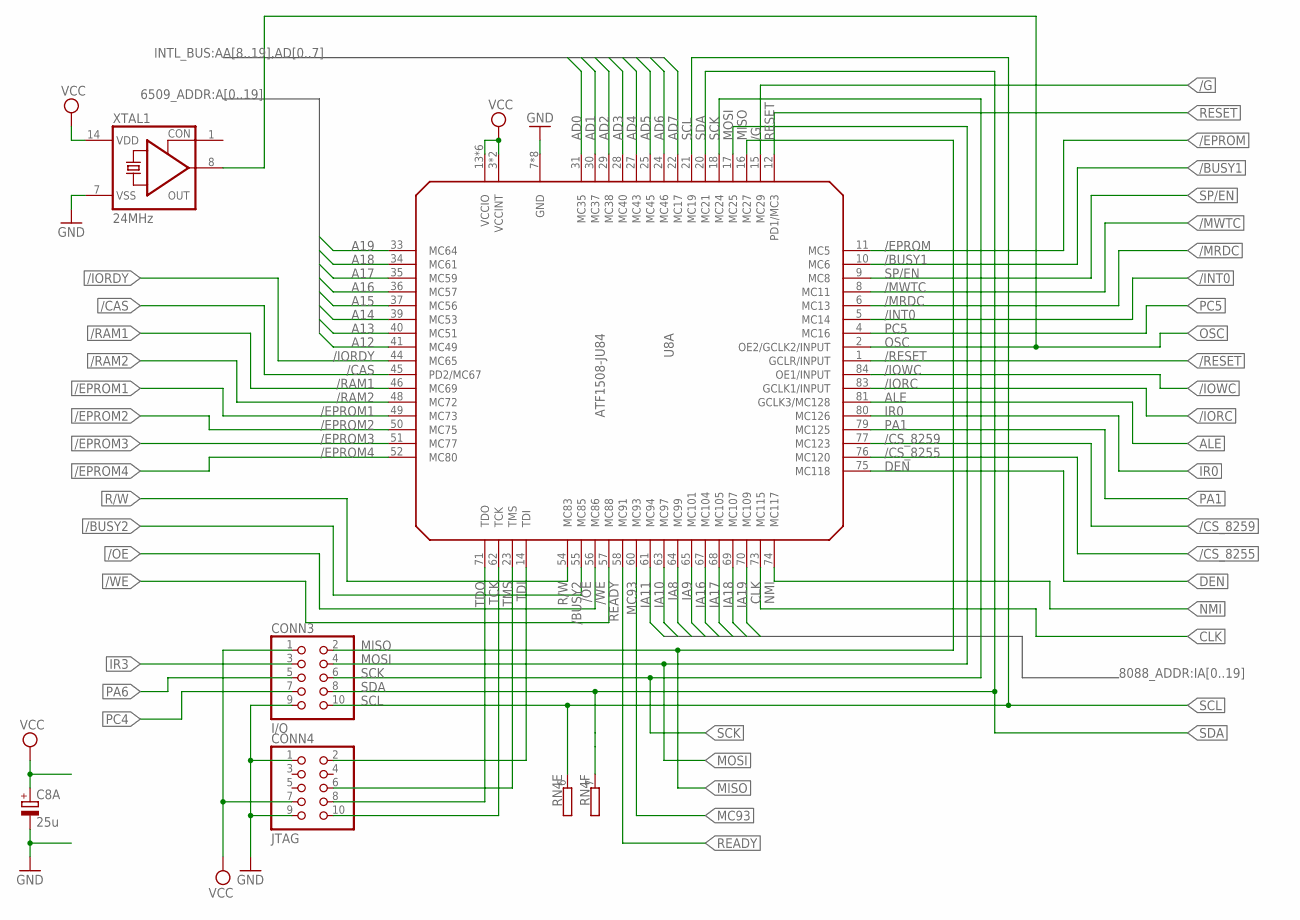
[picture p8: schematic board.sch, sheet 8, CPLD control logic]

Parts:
C8A: 25u; E5-6
CONN3: I/O; 2X05
CONN4: JTAG; 2X05
RN4: GE08R; SIL9
U8A: ATF1508-JU84; S84
XTAL1: 24MHz; SG51

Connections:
/BUSY1: U8A.10 (MC6); also elsewhere on the board
/BUSY2: U8A.55 (MC85); also elsewhere on the board
/CAS: U8A.45 (PD2/MC67); also elsewhere on the board
/CS_8255: U8A.76 (MC120); also elsewhere on the board
/CS_8259: U8A.77 (MC123); also elsewhere on the board
/EPROM: U8A.11 (MC5); also elsewhere on the board
/EPROM1: U8A.49 (MC73); also elsewhere on the board
/EPROM2: U8A.50 (MC75); also elsewhere on the board
/EPROM3: U8A.51 (MC77); also elsewhere on the board
/EPROM4: U8A.52 (MC80); also elsewhere on the board
/G: U8A.15 (MC29); also elsewhere on the board
/INT0: U8A.5 (MC14); also elsewhere on the board
/IORC: U8A.83 (GCLK1/INPUT); also elsewhere on the board
/IORDY: U8A.44 (MC65); also elsewhere on the board
/IOWC: U8A.84 (OE1/INPUT); also elsewhere on the board
/MRDC: U8A.6 (MC13); also elsewhere on the board
/MWTC: U8A.8 (MC11); also elsewhere on the board
/OE: U8A.56 (MC86); also elsewhere on the board
/RAM1: U8A.46 (MC69); also elsewhere on the board
/RAM2: U8A.48 (MC72); also elsewhere on the board
/RESET: U8A.1 (GCLR/INPUT); also elsewhere on the board
/WE: U8A.57 (MC88); also elsewhere on the board
A12: U8A.41 (MC49); also elsewhere on the board
A13: U8A.40 (MC51); also elsewhere on the board
A14: U8A.39 (MC53); also elsewhere on the board
A15: U8A.37 (MC56); also elsewhere on the board
A16: U8A.36 (MC57); also elsewhere on the board
A17: U8A.35 (MC59); also elsewhere on the board
A18: U8A.34 (MC61); also elsewhere on the board
A19: U8A.33 (MC64); also elsewhere on the board
AD0: U8A.31 (MC35); also elsewhere on the board
AD1: U8A.30 (MC37); also elsewhere on the board
AD2: U8A.29 (MC38); also elsewhere on the board
AD3: U8A.28 (MC40); also elsewhere on the board
AD4: U8A.27 (MC43); also elsewhere on the board
AD5: U8A.25 (MC45); also elsewhere on the board
AD6: U8A.24 (MC46); also elsewhere on the board
AD7: U8A.22 (MC17); also elsewhere on the board
ALE: U8A.81 (GCLK3/MC128); also elsewhere on the board
CLK: U8A.73 (MC115); also elsewhere on the board
DEN: U8A.75 (MC118); also elsewhere on the board
GND: C8A.-, CONN3.9, CONN4.1, CONN4.9, U8A.7 (GND), U8A.19 (GND), U8A.32 (GND), U8A.42 (GND), U8A.47 (GND), U8A.59 (GND), U8A.72 (GND), U8A.82 (GND), XTAL1.7 (VSS); also elsewhere on the board
IA8: U8A.64 (MC99); also elsewhere on the board
IA9: U8A.65 (MC101); also elsewhere on the board
IA10: U8A.63 (MC97); also elsewhere on the board
IA11: U8A.61 (MC94); also elsewhere on the board
IA16: U8A.67 (MC104); also elsewhere on the board
IA17: U8A.68 (MC105); also elsewhere on the board
IA18: U8A.69 (MC107); also elsewhere on the board
IA19: U8A.70 (MC109); also elsewhere on the board
IR0: U8A.80 (MC126); also elsewhere on the board
IR3: CONN3.3; also elsewhere on the board
MC93: U8A.60 (MC93); also elsewhere on the board
MISO: CONN3.2, U8A.16 (MC27); also elsewhere on the board
MOSI: CONN3.4, U8A.17 (MC25); also elsewhere on the board
NMI: U8A.74 (MC117); also elsewhere on the board
OSC: U8A.2 (OE2/GCLK2/INPUT), XTAL1.8 (OUT); also elsewhere on the board
PA1: U8A.79 (MC125); also elsewhere on the board
PA6: CONN3.5; also elsewhere on the board
PC4: CONN3.7; also elsewhere on the board
PC5: U8A.4 (MC16); also elsewhere on the board
R/W: U8A.54 (MC83); also elsewhere on the board
READY: U8A.58 (MC91); also elsewhere on the board
RESET: U8A.12 (PD1/MC3); also elsewhere on the board
SCK: CONN3.6, U8A.18 (MC24); also elsewhere on the board
SCL: CONN3.10, RN4.6 (2), U8A.21 (MC19); also elsewhere on the board
SDA: CONN3.8, RN4.7 (2), U8A.20 (MC21); also elsewhere on the board
SP/EN: U8A.9 (MC8); also elsewhere on the board
TCK: CONN4.10, U8A.62 (TCK)
TDI: CONN4.2, U8A.14 (TDI)
TDO: CONN4.8, U8A.71 (TDO)
TMS: CONN4.6, U8A.23 (TMS)
VCC: C8A.+, CONN3.1, CONN4.7, U8A.3 (VCCINT), U8A.13 (VCCIO), U8A.26 (VCCIO), U8A.38 (VCCIO), U8A.43 (VCCINT), U8A.53 (VCCIO), U8A.66 (VCCIO), U8A.78 (VCCIO), XTAL1.14 (VDD); also elsewhere on the board

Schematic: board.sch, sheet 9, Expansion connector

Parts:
CONN5: ISA; 2X30
RN4: GE08R; SIL9

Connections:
+12V: CONN5.15; also elsewhere on the board
-12V: CONN5.11; also elsewhere on the board
/AIOWC: CONN5.23; also elsewhere on the board
/AMWC: CONN5.19; also elsewhere on the board
/IORC: CONN5.25; also elsewhere on the board
/IORDY: CONN5.18, RN4.4 (2); also elsewhere on the board
/IOWC: CONN5.55; also elsewhere on the board
/MRDC: CONN5.21; also elsewhere on the board
/MWTC: CONN5.20; also elsewhere on the board
AD0: CONN5.16; also elsewhere on the board
AD1: CONN5.14; also elsewhere on the board
AD2: CONN5.12; also elsewhere on the board
AD3: CONN5.10; also elsewhere on the board
AD4: CONN5.8; also elsewhere on the board
AD5: CONN5.6; also elsewhere on the board
AD6: CONN5.4; also elsewhere on the board
AD7: CONN5.2; also elsewhere on the board
ALE: CONN5.53; also elsewhere on the board
CLK: CONN5.37; also elsewhere on the board
GND: CONN5.59; also elsewhere on the board
IA0: CONN5.60; also elsewhere on the board
IA1: CONN5.58; also elsewhere on the board
IA2: CONN5.56; also elsewhere on the board
IA3: CONN5.54; also elsewhere on the board
IA4: CONN5.52; also elsewhere on the board
IA5: CONN5.50; also elsewhere on the board
IA6: CONN5.48; also elsewhere on the board
IA7: CONN5.46; also elsewhere on the board
IA8: CONN5.44; also elsewhere on the board
IA9: CONN5.42; also elsewhere on the board
IA10: CONN5.40; also elsewhere on the board
IA11: CONN5.38; also elsewhere on the board
IA12: CONN5.36; also elsewhere on the board
IA13: CONN5.34; also elsewhere on the board
IA14: CONN5.32; also elsewhere on the board
IA15: CONN5.30; also elsewhere on the board
IA16: CONN5.28; also elsewhere on the board
IA17: CONN5.26; also elsewhere on the board
IA18: CONN5.24; also elsewhere on the board
IA19: CONN5.22; also elsewhere on the board
IR3: CONN5.47; also elsewhere on the board
IR4: CONN5.45; also elsewhere on the board
IR5: CONN5.41; also elsewhere on the board
IR6: CONN5.39; also elsewhere on the board
MC93: CONN5.27; also elsewhere on the board
MISO: CONN5.31; also elsewhere on the board
MOSI: CONN5.33, RN4.9 (2); also elsewhere on the board
OSC: CONN5.57; also elsewhere on the board
PA2: CONN5.5, RN4.5 (2); also elsewhere on the board
PA6: CONN5.13; also elsewhere on the board
PA7: CONN5.17, RN4.2; also elsewhere on the board
PC3: CONN5.43; also elsewhere on the board
PC4: CONN5.9; also elsewhere on the board
PC7: CONN5.7; also elsewhere on the board
RESET: CONN5.1; also elsewhere on the board
SCK: CONN5.29, RN4.8 (2); also elsewhere on the board
SCL: CONN5.51; also elsewhere on the board
SDA: CONN5.49; also elsewhere on the board
SQW: CONN5.35; also elsewhere on the board
VCC: CONN5.3, RN4.1; also elsewhere on the board

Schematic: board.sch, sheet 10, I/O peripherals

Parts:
C10A, C10B, C10C, C10D: 100n; C050-025X075
C10E: 25u; E5-6
G1: CR2032V
IC1: LP2950Z; TO92
J1: SDCARD; SDCMF-10915W010
JP1: JP1E; JP1
LED1, LED2: LEDSQR5.7X3.2; U57X32
R1, R2: 4.7k; 0207/10
RN4: GE08R; SIL9
U10A: 4050N; DIL16
U10B: DS1307; DIL08
U10C: 24C64P; DIL8
XTAL2: CRYSTALTC38H; TC38H

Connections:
+3V3: C10A.1, C10E.+, IC1.1 (O), J1.4 (VDD), LED1.A, R2.2, U10A.1 (VDD)
/BUSY2: U10A.9 (I); also elsewhere on the board
BATT: G1.+, U10B.3 (VBAT)
CS': J1.1 (CD/DAT3/CS), U10A.6 (O)
GND: C10A.2, C10B.2, C10C.2, C10D.2, C10E.-, G1.-, IC1.2 (GND), J1.3 (VSS1), J1.6 (VSS2), J1.M1 (GND), J1.M2 (GND), J1.M3 (GND), J1.M4 (GND), LED2.K (C), R1.1, U10A.8 (VSS), U10B.4 (GND), U10C.2 (A1), U10C.3 (A2), U10C.4 (GND), U10C.7 (WP); also elsewhere on the board
LED1: LED1.K (C), U10A.10 (O)
LED2: LED2.A, U10A.12 (O)
MISO: J1.7 (DAT0/DO), R2.1; also elsewhere on the board
MOSI: U10A.3 (I); also elsewhere on the board
MOSI': J1.2 (CMD/DI), U10A.2 (O)
unnamed: JP1.2, R1.2, U10C.1 (A0)
PC0: U10A.11 (I); also elsewhere on the board
PC7: U10A.7 (I); also elsewhere on the board
SCK: U10A.5 (I); also elsewhere on the board
SCK': J1.5 (CLK/SCLK), U10A.4 (O)
SCL: C10D.1, U10B.6 (SCL), U10C.6 (SCL); also elsewhere on the board
SDA: U10B.5 (SDA), U10C.5 (SDA); also elsewhere on the board
SQW: RN4.3 (2), U10B.7 (SQW); also elsewhere on the board
VCC: C10B.1, C10C.1, IC1.3 (I), JP1.1, U10B.8 (VCC), U10C.8 (VCC); also elsewhere on the board
XTAL1: U10B.1 (X1), XTAL2.2
XTAL2: U10B.2 (X2), XTAL2.1

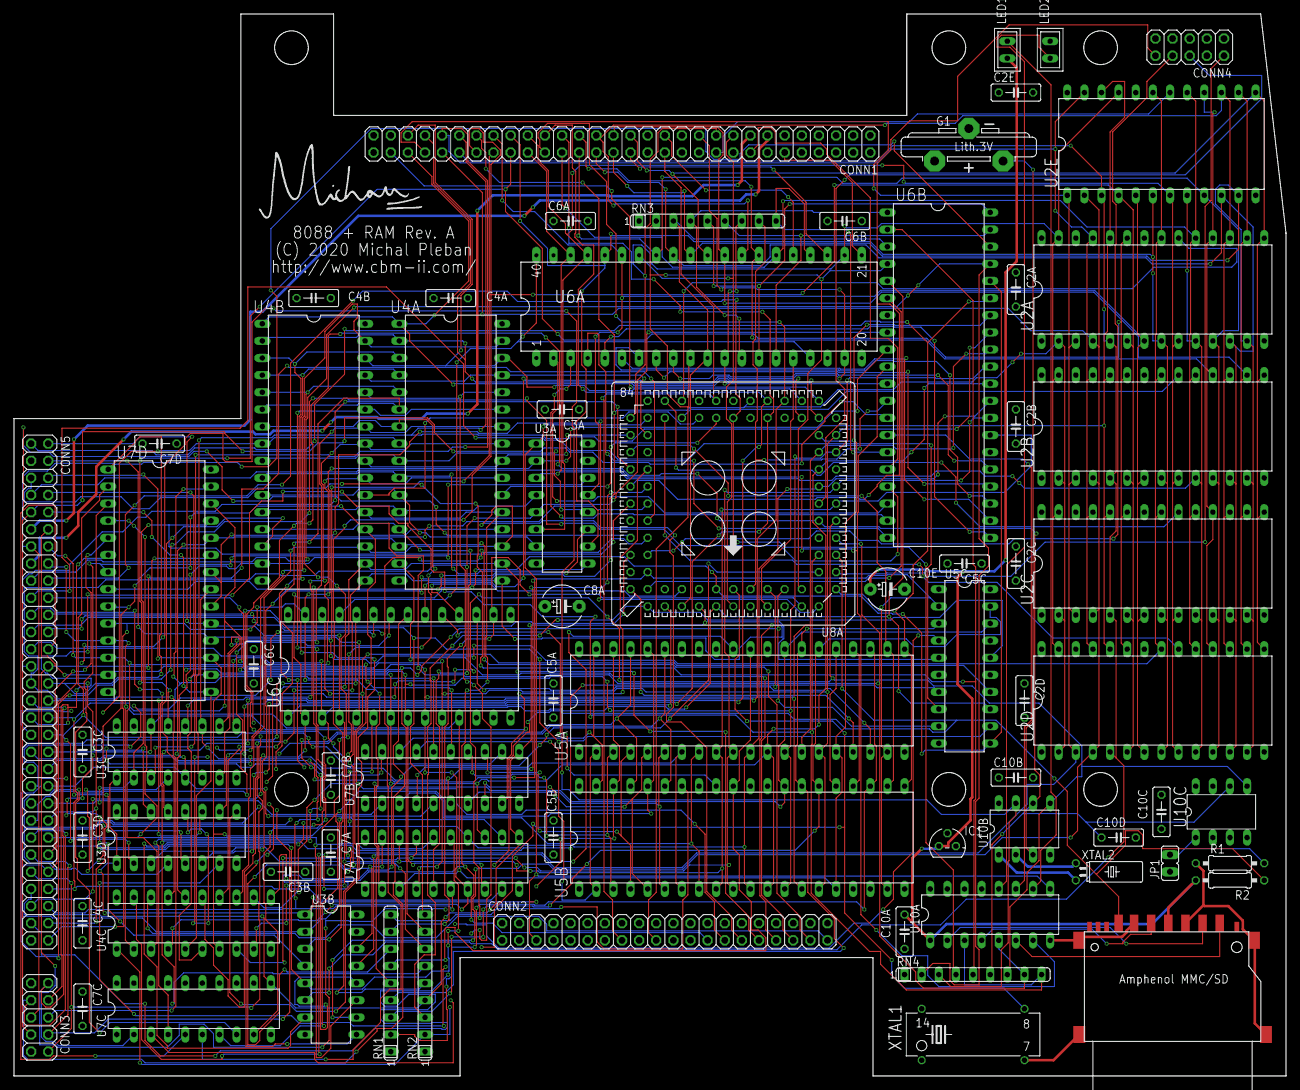
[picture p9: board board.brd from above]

Board: 4 copper layers, 188.7 x 157.5 mm, 73 parts (0 on the bottom side), 197 nets.

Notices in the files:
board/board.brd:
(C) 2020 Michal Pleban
